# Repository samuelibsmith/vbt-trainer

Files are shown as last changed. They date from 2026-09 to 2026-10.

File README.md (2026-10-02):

# VBT Trainer

A DIY velocity-based training (VBT) device that measures barbell speed in real time. A spring-loaded spool with a 600 PPR rotary encoder measures bar displacement, and an ESP32 turns that into velocity, rep metrics, an on-device display, BLE output, and CSV logs.

## What it does

- Measures barbell velocity (±2% accuracy target) using a spring-loaded

  spool and 600 PPR rotary encoder

- Streams live velocity data over BLE to a phone app

- Logs session data to CSV for analysis

- Computes: MCV, peak velocity, velocity loss %, estimated 1RM, (using weight lifted: peak power, avg power)

## Hardware

| Microcontroller | ESP32 DevKit v1 | $9 | 

| Encoder | Taiss 600PPR | $18 | 

| Display | SSD1306 0.96" OLED | $3 |

| Battery | Samsung 30Q 18650 3000mAh 15A Battery | $4 |

| Battery Holder | Samsung 30Q 18650 3000mAh 15A Battery | $10 |

Full list: [`hardware/v_1_bom.csv`](hardware/v_1_bom.csv)

## Wiring

| Signal | ESP32 pin | Notes |
|---|---|---|
| Encoder channel A | GPIO 18 | 10 kOhm pull-up to 3.3 V |
| Encoder channel B | GPIO 19 | 10 kOhm pull-up to 3.3 V |
| OLED SDA | GPIO 21 | I2C address 0x3C |
| OLED SCL | GPIO 22 | |
| Reset button | GPIO 4 | <!-- TODO: to GND with internal pull-up? confirm from main.cpp --> |
| Battery + | Vin | also powers the encoder directly |

Pins are defined in [`firmware/include/config.h`](firmware/include/config.h). Wiring notes: [`docs/wiring_diagram.md`](docs/wiring_diagram.md).

> **Power warning:** the current design connects a bare 18650 directly to Vin with no protection circuit or charger. Use a protected cell or a charger/protection module, and never leave the cell unattended while charging. Expect voltage sag (and possible brownouts) as the cell nears empty.

## Getting started

### 1. Build the hardware
1a. Circuitry
Wire everything per the table above. Measure your own spool's effective diameter, because it sets the mm-per-count scale for every reading.
1b. 3D-Printed Housing
Unless you use the exact same tape measure internals from a (Ace 12 ft. L X 3/4 in. W Compact Tape Measure 1 pk), you will need to redesign both the key that translates torque from the spool to the encoder, and the spacing of encoder and the spool. The 3D model of the spool is a 3D replica of the actual spool, with the same measurements. If you order the same spool, the 3D-printed housing is good to go as is. 

### 2. Flash the firmware
Requirements: VS Code with the PlatformIO extension (or the `pio` CLI).

1. Open the `firmware/` folder in PlatformIO. Libraries install automatically from `platformio.ini`.
2. Set `SPOOL_DIAMETER_MM` in `firmware/include/config.h` to your measured spool diameter (the repo default is 37.47).
3. Build and upload: `pio run -t upload`
4. Open the serial monitor at 115200 baud to confirm output: `pio device monitor`

Key settings in `config.h`:

| Setting | Default | Meaning |
|---|---|---|
| `SAMPLE_RATE_HZ` | 200 | velocity calculation rate |
| `SMOOTHING_WINDOW` | 5 | moving-average length (samples) |
| `REP_START_VELOCITY` | 0.08 m/s | rep begins above this |
| `REP_END_VELOCITY` | 0.05 m/s | rep ends below this |
| `REP_MIN_DURATION_MS` | 150 | ignore shorter spikes |
| `BLE_BROADCAST_HZ` | 10 | BLE update rate |

### 3. Log data
Requires Python 3.9-3.12 (the pinned numpy 1.26 has no wheels for 3.13).

```bash
python -m venv .venv
source .venv/bin/activate        # Windows: .venv\Scripts\activate
pip install -r python/requirements.txt

python python/serial_logger.py

## Build Log

- [X] Phase 1: Sensor validation

- [ ] Phase 2: Firmware + Python pipeline

- [ ] Phase 3: Housing design and fabrication

- [ ] Phase 4: Phone app + dashboard

## License

MIT - see [LICENSE](LICENSE).

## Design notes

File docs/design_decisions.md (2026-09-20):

# Design Decisions Log

A running log of non-obvious choices made during the VBT build.

---

## Sensor: Linear transducer vs IMU

**Decision:** Linear position transducer (spool + rotary encoder)

**Reason:** IMUs require double-integration of acceleration to get position, which introduces significant drift. Direct position measurement via encoder gives cleaner velocity signal with no drift. Same method used by GymAware.

## Encoder: Signswise 600 PPR

**Decision:** 600 PPR incremental quadrature encoder

**Reason:** At 600 PPR with ~30mm spool, resolution is ~0.16mm per pulse. This is sufficient for barbell velocities (0.1–2.0 m/s). Higher PPR unnecessary and increases ESP32 interrupt load.

## Voltage: Pull-ups to 3.3V

**Decision:** 10kΩ pull-up resistors tied to 3.3V rail, not 5V 

**Reason:** ESP32 GPIO pins are not 5V tolerant. Pulling up to 3.3V keeps output signal within safe range without needing a level shifter.

## Smoothing: 5-sample moving average

**Decision:** Moving average with window size 5

**Reason:** TBD — will tune empirically during calibration testing.

## Spool: Ace Hardware 12' Tape Measure Spring-loaded spool

**Decision:** Choosing an existing spring-loaded spool versus a custom design

**Reason:** Tape measure retraction spools are a solved problem. The spring-loaded mechanism has plenty of power to retract a fishing line. The cost ~$9 is much more reasonable for a prototype than a custom design.

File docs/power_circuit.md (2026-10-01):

# Power Circuit (v1 redesign: protected single-cell supply)

Status: **design, not yet built or tested.** Verify every IC pin number against the manufacturer datasheets before ordering a PCB.

## Goals
- Inserting the 18650 backwards causes no damage
- Cell is protected against over-discharge, over-current, and short circuit
- The ESP32 and encoder get a stable 5 V rail across the full cell range (about 3.0-4.2 V)

## Block diagram

```
Holder+ -> Q1 (reverse-polarity PMOS) -> F1 (PTC) -> SW1 -> U2 (5 V boost) -> +5V -> ESP32 VIN, encoder
Holder- -> B- -> [Q2 FS8205A, controlled by U1 DW01A] -> GND (P-)
                                                          ESP32 3V3 -> OLED, encoder pull-ups
```

The protection IC switches the **negative** leg, so the positive rail is simply the output of Q1.

## Nets

| Net | Description |
|-----|---|
| `CELL+` | Holder positive contact |
| `B-` | Holder negative contact (cell side of the protection MOSFETs) |
| `VBAT` | Protected battery positive, after Q1 |
| `GND` | System ground (P-, load side of the protection MOSFETs) |
| `VSW` | VBAT after F1 and SW1 |
| `+5V` | Boost converter output |
| `+3V3` | ESP32 onboard 3.3 V output (used by OLED and pull-ups) |

## Bill of materials

| Ref | Part | Value / model | Package | Notes |
|-----|---|---|---|---|
| BT1 | Single 18650 holder | - | - | Use a protected or unprotected cell; this circuit adds protection either way |
| Q1 | P-channel MOSFET | AO3401A (or similar, Vgs(th) under 1.5 V, Rds(on) under 100 mOhm) | SOT-23 | Reverse-polarity protection |
| U1 | Battery protection IC | DW01A | SOT-23-6 | Over-discharge, over-current, short circuit |
| Q2 | Dual N-MOSFET | FS8205A (8205A) | TSSOP-8 | Pairs with U1 |
| R1 | Resistor | 100 Ohm | 0603 | U1 supply filter |
| R2 | Resistor | 1 kOhm | 0603 | U1 current-sense input |
| C1 | Capacitor | 0.1 uF | 0603 | U1 supply decoupling |
| F1 | Resettable fuse (PTC) | about 1.5 A hold | 1812 or radial | Last-resort overcurrent limit |
| SW1 | Slide switch | SPDT, rated 1 A or more | - | Main power switch |
| U2 | 5 V boost converter | Module or IC, at least 0.5 A output at 3.0 V input (e.g. Pololu U1V11F5) | - | Check the datasheet for input-current limits |
| C2 | Capacitor | 10 uF | 0805 | Optional: extra bulk at U2 input |
| R3, R4 | Resistors | 10 kOhm | 0603 | Encoder A/B pull-ups to 3V3 |
| U3 | ESP32 DevKit v1 | - | - | 30-pin DevKit v1 |
| DS1 | OLED | SSD1306 0.96" I2C | - | 4-pin module |
| ENC1 | Rotary encoder | 600 P/R, 2-channel, NPN open-collector, 5-24 V | - | See wiring below |
| SW2 | Momentary button | - | - | Reset / rep button on GPIO 4 |

## Wiring

### Reverse-polarity protection

| From | To |
|---|----|
| BT1 + (`CELL+`) | Q1 **drain** (SOT-23 pin 3) |
| Q1 **source** (pin 2) | `VBAT` |
| Q1 **gate** (pin 1) | `GND` |

Correct insertion turns Q1 on. Reversed, Q1 stays off and blocks current.

### Cell protection (U1, Q2)

| From | To | Notes |
|---|----|---|
| `VBAT` | R1 (100 Ohm), then U1 pin 5 (VCC) | |
| C1 | U1 VCC to U1 GND | Place close to U1 |
| U1 pin 6 (GND) | `B-` | |
| U1 pin 1 (OD) | Q2 pin 4 (G1) | Over-discharge gate |
| U1 pin 3 (OC) | Q2 pin 5 (G2) | Over-charge gate |
| U1 pin 2 (CS) | R2 (1 kOhm), then `GND` | Current sense |
| U1 pin 4 (TD) | not connected | Test pin |
| Q2 pins 2, 3 (S1) | `B-` | |
| Q2 pins 6, 7 (S2) | `GND` | |
| Q2 pins 1, 8 (D) | tie together, no other connection | Shared drain |
| BT1 - | `B-` | |

### Power path

| From | To |
|---|----|
| `VBAT` | F1 |
| F1 | SW1 common |
| SW1 output (`VSW`) | U2 VIN |
| U2 GND | `GND` |
| U2 VOUT (`+5V`) | ESP32 **VIN** pin |
| ESP32 GND | `GND` |

### Encoder (ENC1)

NPN open-collector outputs only pull a signal to ground, so each output needs a pull-up. **Pull up to 3.3 V, never 5 V**, because ESP32 GPIOs are not 5 V tolerant.

| Encoder wire (typical colors, verify on your unit) | To |
|---|----|
| Red (V+) | `+5V` |
| Black (0 V) | `GND` |
| Green (A) | ESP32 GPIO 18, and R3 (10 kOhm) to `+3V3` |
| White (B) | ESP32 GPIO 19, and R4 (10 kOhm) to `+3V3` |
| Shield (if present) | `GND` |

### Display (DS1) and button

| From | To |
|---|----|
| DS1 VCC | `+3V3` |
| DS1 GND | `GND` |
| DS1 SDA | ESP32 GPIO 21 |
| DS1 SCL | ESP32 GPIO 22 |
| SW2 one side | ESP32 GPIO 4 |
| SW2 other side | `GND` (assumed, confirm against `main.cpp`) |

## Bring-up checklist
1. Inspect all joints. Check continuity that `VBAT` and `GND` are not shorted, with no cell installed.
2. With SW1 **off**, insert the cell **backwards** deliberately. Measure `VBAT` and `+5V`: both should read about 0 V and nothing should get warm. Remove the cell.
3. Insert the cell correctly, SW1 still off. `VBAT` should read the cell voltage.
4. Turn SW1 on. `+5V` should read about 5 V and the ESP32 should boot.
5. Confirm encoder counts and display before doing anything else.

## Notes and limits
- **Charging is external.** Charge the cell in a separate 18650 charger. Adding an onboard TP4056-class charger is a future revision.
- **Keep SW1 off when connecting USB** so the USB supply and boost converter do not feed VIN together.
- **Protection cutoffs** for DW01A are around 2.4 V (over-discharge) with an over-current trip of several amps; check the datasheet for exact thresholds.
- This is a hobby design that has not been independently reviewed. Treat it as a starting point and do not leave a lithium cell unattended while testing.

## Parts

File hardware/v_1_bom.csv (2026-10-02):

Ref | Qty | Part | Key spec | Notes | Link to Buy
U3 | 1 | ESP32 DevKit v1 | ESP32-WROOM-32, USB, 3V3 and VIN pins | 30-pin or 38-pin both work | http://amazon.com/Development-Compatible-Supports-Dual-Core-Microcontroller/dp/B0FPLS7XDM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
ENC1 | 1 | Rotary encoder | 600 P/R, 2-channel, NPN open-collector, 5-24 V, 6 mm shaft |  | https://www.amazon.com/dp/B07JM9YRTQ?lv=shuf&channelId=500&plpRedirect=mhFallback
DS1 | 1 | OLED display | SSD1306, 0.96 in, 128x64, I2C | Firmware uses address 0x3C | amazon.com/UCTRONICS-SSD1306-Self-Luminous-Display-Raspberry/dp/B072Q2X2LL/ref=sr_1_6?crid=3DOX8Y4UI2PD6&dib=eyJ2IjoiMSJ9.z259gjIsNpIAfONgHGpTbSRqoqPFDFXhWZRag8Bblgf4_0T06BFWpd2v7jx2iUymEyqv1FezfHEzqE_sTzU-TVdDscfZy7ZZ69cgJI0-vkZ_2_5oocDjsiddisiYbPTWiEp0MKLVdsu6boR2DG2ubOv-elv5FY_U-ATUU9SR3mC2mE51OYS6bWM72Ub06_ofopWxcF1VX9CpeYeNmFi8sbJeN4LFR0jhabFZz91flq4.BYX3qmEq7juO6cMsYyJv2QjN2FNC9sa0lZnExs5kk6Y&dib_tag=se&keywords=SSD1306%2C+0.96+in%2C+128x64%2C+I2C&qid=1790949157&sprefix=ssd1306%2C+0.96+in%2C+128x64%2C+i2c%2Caps%2C177&sr=8-6
BT1 | 1 | 18650 cell (protected) | Li-ion about 3000 mAh, built-in protection board | Check length fits the holder | https://www.18650batterystore.com/products/samsung-30q
 | 1 | Single 18650 holder |  |  | https://www.amazon.com/FORIOT-Battery-Compartment-Support-Charging/dp/B0CJR1Y967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
Q1 | 1 | AO3401A P-channel MOSFET | SOT-23, -30 V, about -4 A | Alternative: SI2301; Reverse-polarity protection | https://www.digikey.com/en/products/detail/alpha-omega-semiconductor-inc/AO3401A/1855773
F1 | 1 | Resettable fuse (PTC) | About 1.5 A hold | Optional - can find own if wanting to add the current protection
SW1 | 1 | Power switch | Rated 2 A or more | Optional - can find own if wanting to add the current protection
U2 | 1 | 5 V boost converter | At least 0.5 A output at 3.0 V input | e.g. Pololu U1V11F5; check datasheet | https://www.pololu.com/product/2562
SW2 | 1 | Momentary push button |  | Reset button on GPIO 4 | https://www.dfrobot.com/product-612.html
R3, R4 | 2 | Resistor | 10 kOhm 1/4 W | Encoder A/B pull-ups to 3V3
 | 1 | Spool and spring tether mechanism | 37.47 mm effective diameter | Measure your own spool, but I linked the exact model here | https://www.acehardware.com/departments/tools/measure-and-marking-tools/tape-measures/2037164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
 | 1 | Perfboard or breadboard, hookup wire, connectors
 | 1 | External 18650 charger |  | Charging is off-board in v1
 | 1 | M3x4mm Heat Inserts
 | 1 | M3 assorted screws socket cap head

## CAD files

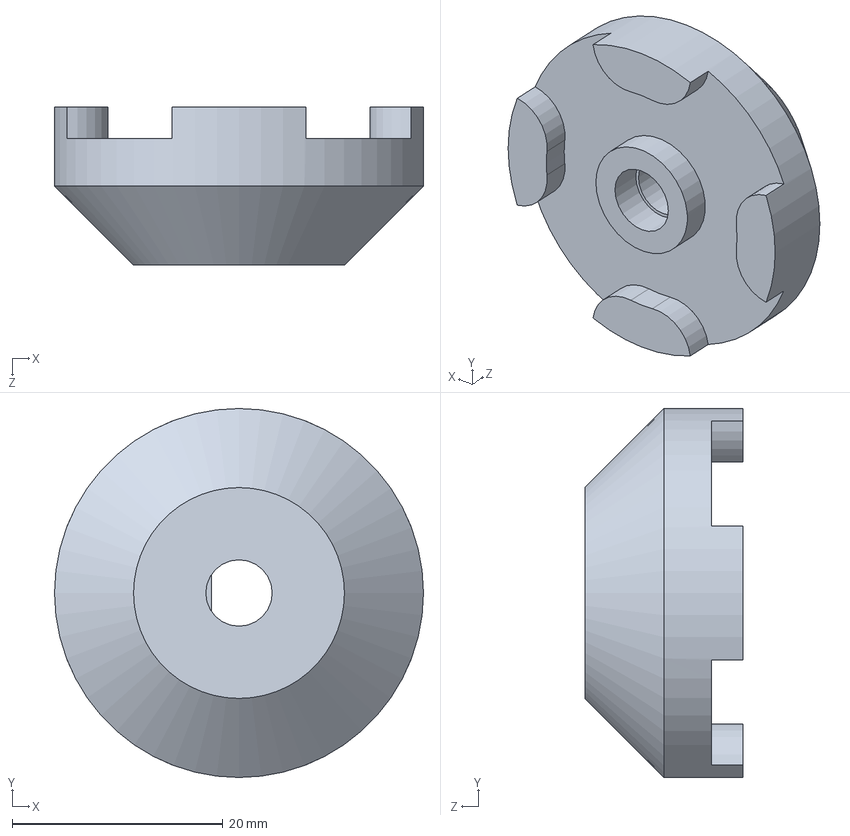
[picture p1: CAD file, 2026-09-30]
hardware/cad/VBT_Encoder_Spool_Key.SLDPRT
35.0 x 35.0 x 15.0 mm

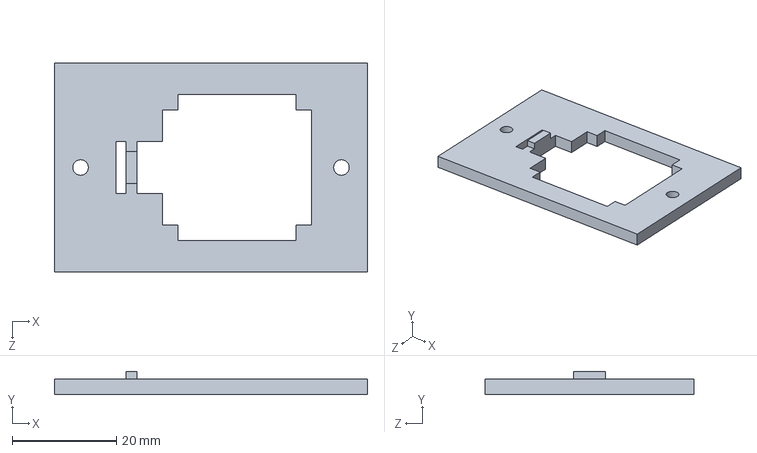
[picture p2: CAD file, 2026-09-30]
hardware/cad/ScreenBracket.SLDPRT
60.0 x 4.50 x 40.0 mm

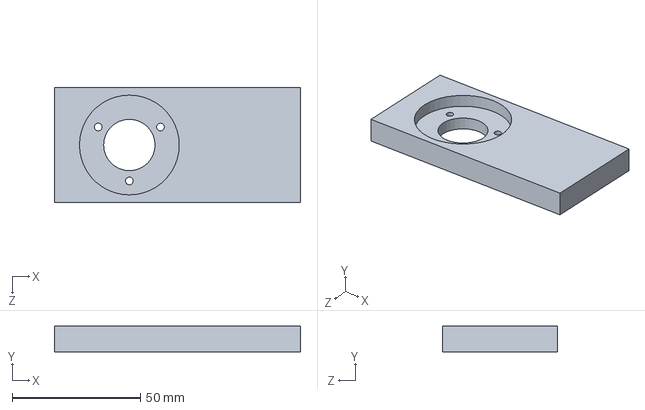
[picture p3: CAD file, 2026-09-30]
hardware/cad/VBT_EncoderSide_Wall.SLDPRT
95.8 x 10.0 x 44.8 mm

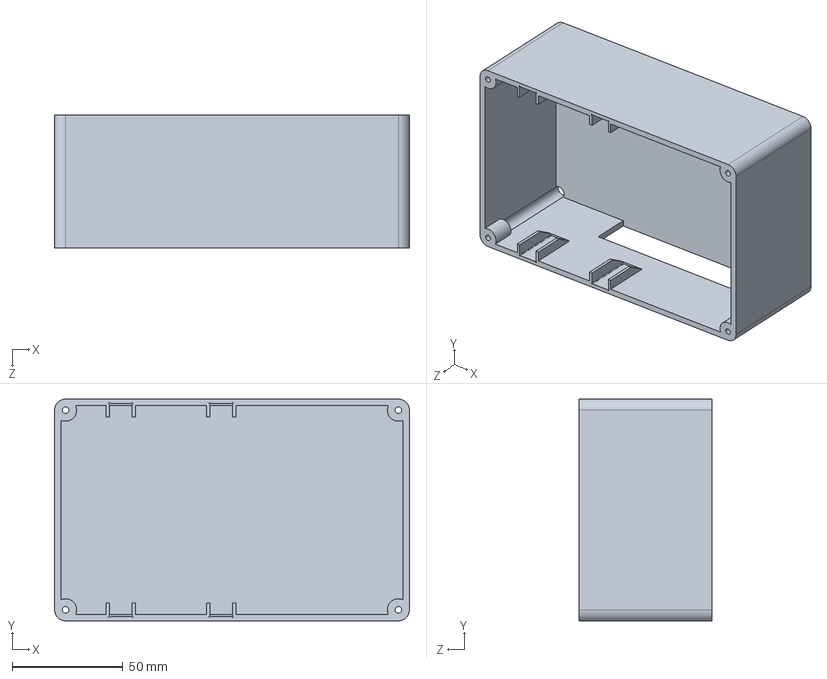
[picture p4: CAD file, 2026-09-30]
hardware/cad/VBT_Container_Base.SLDPRT
160.0 x 100.0 x 60.0 mm

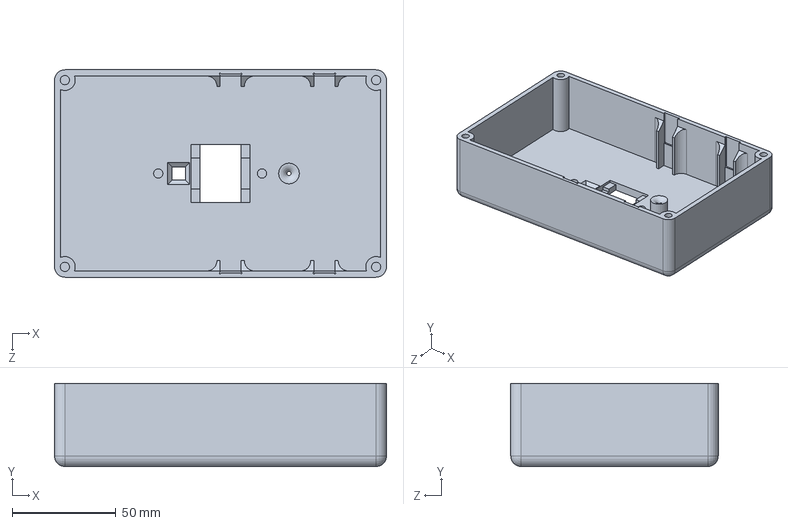
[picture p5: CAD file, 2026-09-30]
hardware/cad/VBT_Container_Lid.SLDPRT
160.0 x 40.0 x 100.0 mm

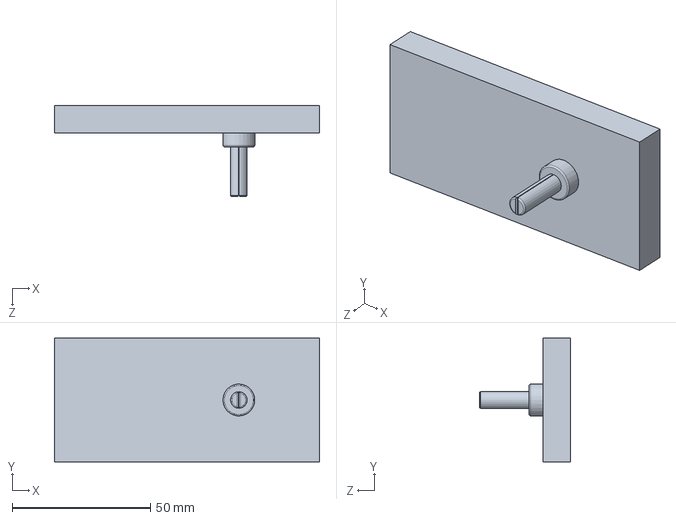
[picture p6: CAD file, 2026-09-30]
hardware/cad/VBT_SpoolSide_Wall.SLDPRT
95.8 x 44.8 x 33.0 mm

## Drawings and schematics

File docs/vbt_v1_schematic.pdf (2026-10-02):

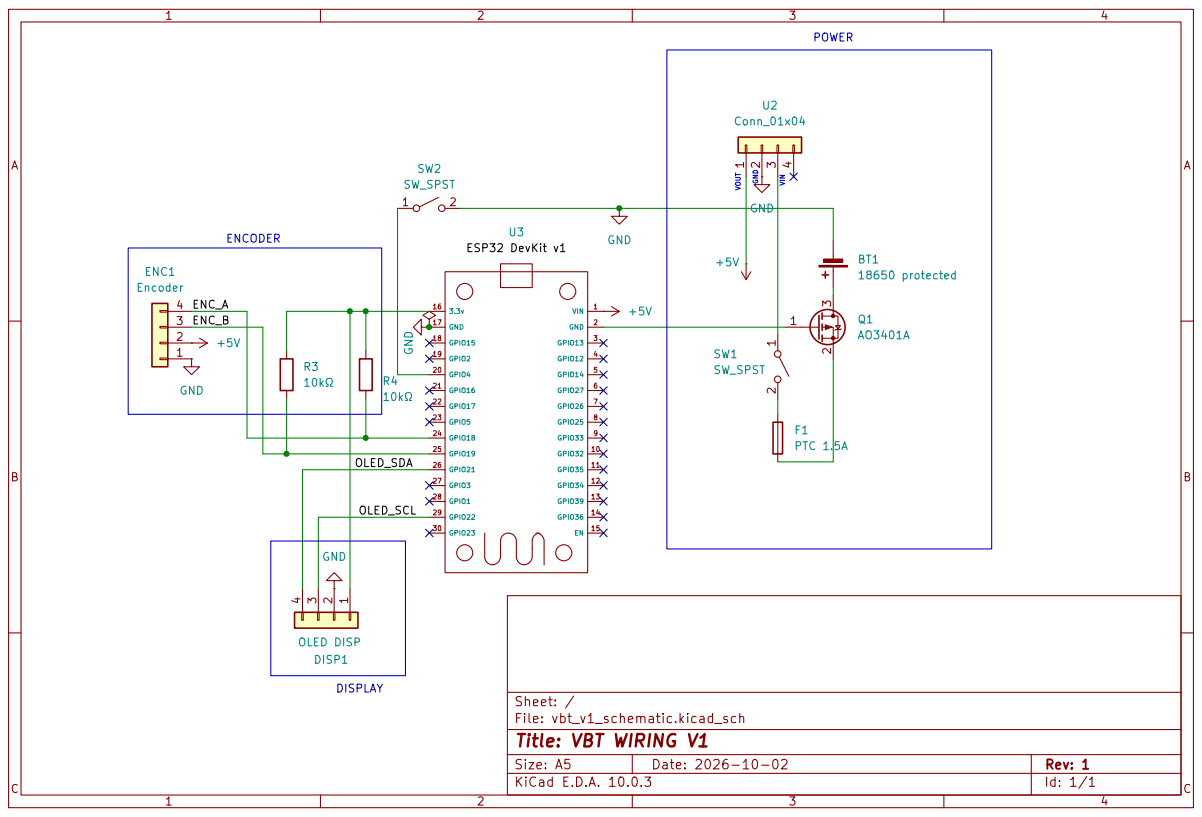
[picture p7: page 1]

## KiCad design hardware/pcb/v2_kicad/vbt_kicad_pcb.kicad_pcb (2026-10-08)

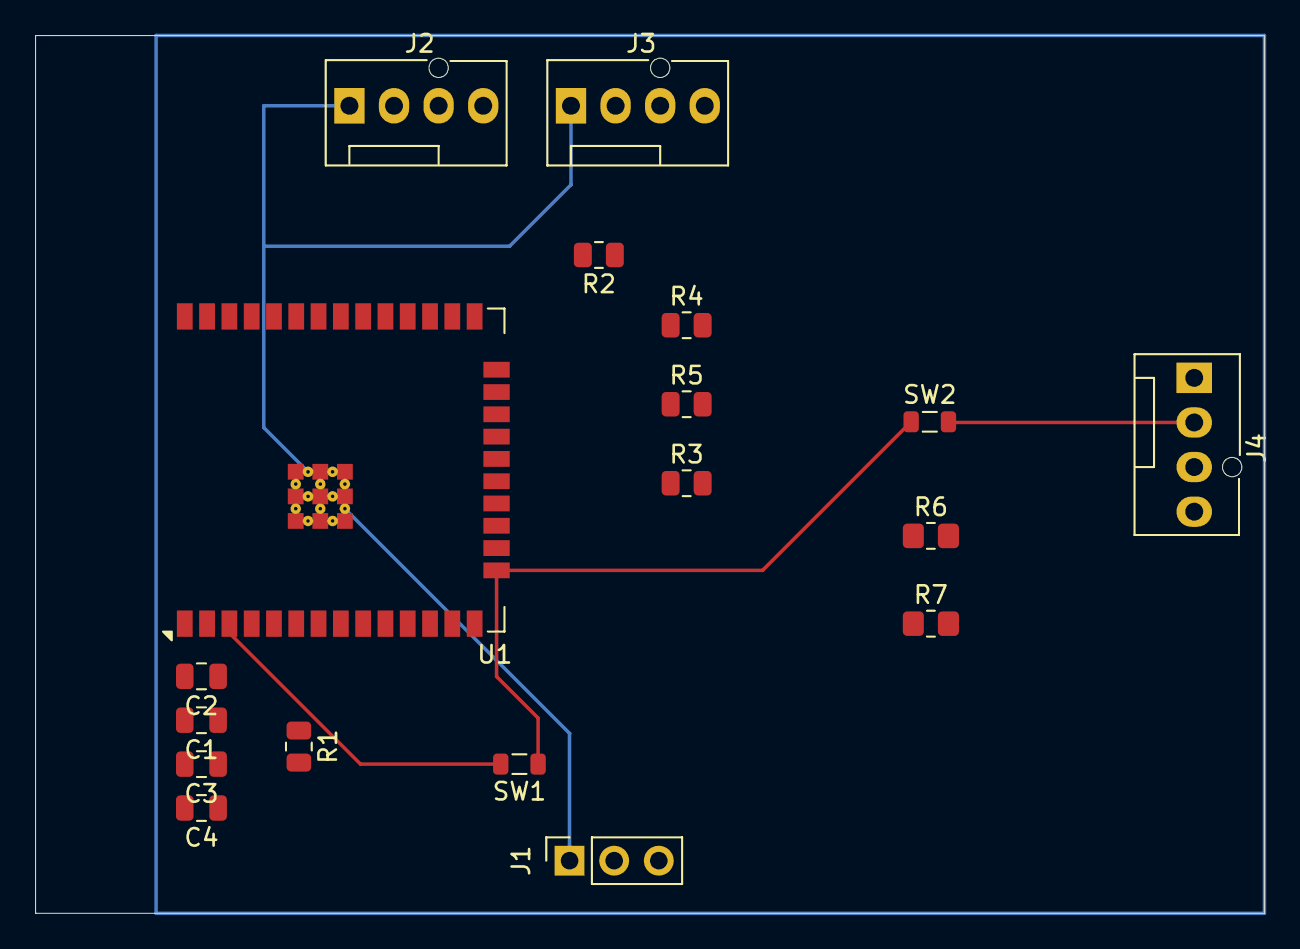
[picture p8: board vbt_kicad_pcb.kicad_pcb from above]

Board: 2 copper layers, 70.0 x 50.0 mm, 18 parts (0 on the bottom side), 10 nets.

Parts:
C1: 10 µF; C_0805_2012Metric
C2: 100 nF; C_0805_2012Metric
C3, C4: 1 µF; C_0805_2012Metric
J1: Conn_01x03; PinSocket_1x03_P2.54mm_Vertical
J2, J3, J4: Conn_01x04; FanPinHeader_1x04_P2.54mm_Vertical
R1, R2: R; R_0805_2012Metric
R3: 10k; R_0805_2012Metric
R4, R5: 4.7k; R_0805_2012Metric
R6, R7: 100k; R_0805_2012Metric_Pad1.20x1.40mm_HandSolder
SW1, SW2: SW_Push; L_0805_2012Metric
U1: ESP32-WROOM-32E

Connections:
+3V3: C1.1, C2.1, J3.2, J4.4, R1.1, R2.1, R3.1, R4.1, R5.1, U1.2 (VDD)
/+5V: J2.2, J4.1
/ENC_A: J2.4, R2.2, U1.30 (IO18)
/ENC_B: J2.3, R3.2, U1.31 (IO19)
/I2C_SCL: J3.4, R5.2, U1.36 (IO22)
/I2C_SDA: J3.3, R4.2, U1.33 (IO21)
/VBAT_SENSE: R6.2, U1.6 (IO34)
GND: C1.2, C2.2, C3.2, C4.1, C4.2, J1.1, J2.1, J3.1, J4.2, R7.1, SW1.1, SW2.1, SW2.2, U1.1 (GND), U1.15 (GND), U1.25 (IO0), U1.38 (GND), U1.39 (GND)
unnamed: J4.3, R6.1, R7.2
unnamed: C3.1, R1.2, SW1.2, U1.3 (EN)

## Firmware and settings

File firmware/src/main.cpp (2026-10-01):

/*
 VBT Trainer Project - Samuel Smith - Spring 2026
sibsmith@bu.edu | sibsmith.ithaca@gmail.com
*/
#include <Arduino.h> // Core: pinMode, digitalRead, millis, Serial
#include <ESP32Encoder.h> // Harware pulse counter -- performs better than interrupts
#include <Adafruit_GFX.h>      // Graphics base library for OLED
#include <Adafruit_SSD1306.h>  // OLED driver
#include <Wire.h> //I2C protocol -- needed for OLED
#include <NimBLEDevice.h> // Bluetooth Low Energy
#include "config.h" //imports custom pin definitions and constants

ESP32Encoder encoder;

// Velocity Tracking
float velocityBuffer[SMOOTHING_WINDOW]; //Circular buffer for moving average
int bufferIndex = 0; //Index for tracking buffer position
float smoothVelocity = 0.0; //Value of the smoothed velocity
float peakVelocity = 0.0; //Highest velocity in the calculated rep window
long lastPulseCount = 0; //Encoder count at last velocity sample
unsigned long lastSampleTime = 0; //Timestamp of last velocity sample (ms)

// Rep detection
bool repInProgress = false; // Checks to see if we are currently in a rep
int repCount = 0; // Total reps in the session
float repStartVelocity = 0.0; // Velocity at the start of the rep 
float meanConcentricVelo = 0.0; //Mean Concentric Velocity for the completed repetition
// **Mean Concentric Velocity (MCV)** Average velocity of the barbell during the rep
float velocitySumThisRep = 0.0; // Sum of the velocity samples during concentric phase
int samplesThisRep = 0; // Number of sampels taken during the concentric phase of the rep
unsigned long repStartTime = 0; // When this rep started (ms)

// Session Tracking
float setPeakVelocity = 0.0; // MCV of the rep with the highest velocity (to calculate velocity loss %)
float velocityLoss = 0.0; // Signed percent change from peak rep to most recent rep
// OLED 
Adafruit_SSD1306 display(128, 64, &Wire, -1);

// Bluetooth LE 
NimBLEServer* bleServer = nullptr;
NimBLECharacteristic* bleCharVelocity = nullptr;
bool bleClientConnected = false;
unsigned long lastBLEUpdate = 0; // timestamp of last BLE broadcast
class ServerCallbacks : public NimBLEServerCallbacks {
    void onConnect(NimBLEServer* server) override {

        bleClientConnected = true;

        Serial.println("BLE: phone connected");

    }
        void onDisconnect(NimBLEServer* server) override {

        bleClientConnected = false;

        Serial.println("BLE: phone disconnected — advertising again");

        server->startAdvertising();  // Auto-restart advertising so phone can reconnect

    }
};

void setupBLE(){
    NimBLEDevice::init(BLE_DEVICE_NAME);  // Initialize with your device name
    bleServer = NimBLEDevice::createServer();
    bleServer->setCallbacks(new ServerCallbacks());
    //Create the service - service being the catagory of data, in this case vbt velocity data
    NimBLEService* service = bleServer->createService(SERVICE_UUID);
    bleCharVelocity = service->createCharacteristic(CHARACTERISTIC_UUID, NIMBLE_PROPERTY::NOTIFY);
    service->start(); 
    // begins advertizing existence so phone can connect 
    NimBLEAdvertising* advertising = NimBLEDevice::getAdvertising();
    advertising->addServiceUUID(SERVICE_UUID);
    advertising->start();
    Serial.println("BLE: advertising as '" BLE_DEVICE_NAME "'");
}
// HELPER FUNCTIONS ---------------------
// calculateVelocity: Returns raw velocity in m/s when called every 200Hz/5ms in loop()
float calculateVelocity() {
    unsigned long now = millis(); // Gets current time in ms
    long nowCount = encoder.getCount(); // Gets the current encoder pulse count
    unsigned long dt_ms = now - lastSampleTime; // Time delta between last sample (ms)
    long dp = (nowCount - lastPulseCount) * CONCENTRIC_SIGN; // Pulses since last sample
    // Update "last" values for next function call
    lastSampleTime = now;
    lastPulseCount = nowCount;
    //Safeguard: if not time has passed, avoide devide-by-zero error
    if (dt_ms == 0) return 0.0;
    //Convert pulses to mm and milliseconds to seconds to get velocity
    //Calculation is (meters/second) = pulses * mm/pulse * 1 meter / 1000 mm * 1000 ms/1s * 1/dt_ms
    float displacement_mm = dp * MM_PER_PULSE; //total mm moved
    float velocity_ms = (displacement_mm/1000.0)/(dt_ms/1000.0); //mm -> meters, ms -> seconds (meters/second)
    //Given we only want the upward velocity, the velocity must have a sign to denote direction
    return velocity_ms;
}

// logToSerial: logs the timestamp (ms), rawVelocity value, and smoothVel value in csv format
void logToSerial(unsigned long timestamp, float rawVelocity, float smoothVel, int rep) {
    // Format: timestamp_ms, raw_velocity, smooth_velocity, rep_number
    Serial.print(timestamp);
    Serial.print(",");
    Serial.print(rawVelocity, 4);   // 4 decimal places
    Serial.print(",");
    Serial.print(smoothVel, 4);
    Serial.print(",");
    Serial.println(rep);            // println adds newline — Python reads line by line
}

//updateDisplay: called after each rep is completed and at every 100ms interval during the rep
void updateDisplay(float mcv, int reps, float velocity, float vLoss) {
    display.clearDisplay(); //Clear display of any existing text
    display.setTextColor(SSD1306_WHITE);
    //LINE 1: Large text displaying LIVE VELOCITY
    display.setTextSize(2); 
    display.setCursor(0, 0);
    display.print(mcv, 2);   // Round velocity to 2 decimal places
    display.print(" m/s");
    //LINE 2: Displays a rep counter for current exercise
    display.setTextSize(1);
    display.setCursor(0, 22);
    display.print("Reps: "); //Prints "reps" before the number that gets updated
    display.print(reps);
    //LINE 3: Last rep MCV
    display.setCursor(0, 32);
    display.print("Peak: ");
    display.print(velocity, 2); //Rounds mcv to 2 decimal places, consistent with velo
    display.print(" m/s");
    // Line 4: Velocity loss %
    display.setCursor(0, 42);
    display.print("VL%: ");
    display.print(vLoss, 1);
    display.print("%");
    // Line 5: BLE status
    display.setCursor(0, 54);
    display.print(bleClientConnected ? "BLE: connected" : "BLE: waiting...");
    display.display(); //Push buffer to screen — nothing shows until this is called
}

//sendBleUpdate: When called, packages current rep data as JSON string 
//formatted as {"v":1.23,"reps":3,"mcv":1.18,"vl":4.2} and sends as BLE packet
void sendBleUpdate(float velocity, int reps, float mcv, float vLoss) {
    if (!bleClientConnected) return;  // Immedate return if not bluetooth connection is established
    // Sample JSON string is as follows: {"v":1.23,"reps":3,"mcv":1.18,"vl":4.2}
    char jsonBuffer[80]; // If number of reps gets too high, this may crash the buffer of only 80
    snprintf(jsonBuffer, sizeof(jsonBuffer),
        "{\"v\":%.2f,\"reps\":%d,\"mcv\":%.2f,\"vl\":%.1f}", velocity, reps, mcv, vLoss);
    bleCharVelocity->setValue((uint8_t*)jsonBuffer, strlen(jsonBuffer));
    bleCharVelocity->notify();  //Push to any subscribed phone
}

// smoothVelocityReading: takes the float of the newest velocity sample "newSample" 
// and returns a new smoothed average given the defined SMOOTHING_WINDOW
float smoothVelocityReading(float newSample){
    velocityBuffer[bufferIndex] = newSample; // Stores new sample
    bufferIndex = (bufferIndex + 1) % SMOOTHING_WINDOW; // Advances buffer index 
    // % (modulus) wraps back to 0
    // Calculate the average of all samples in buffer
    float sum = 0.0;
    for (int i = 0; i<SMOOTHING_WINDOW; i++){
        sum += velocityBuffer[i];
    }
    return sum/SMOOTHING_WINDOW;
}


void setup(){
    //_________________________ SERIAL _________________________
    Serial.begin(115200);
    Serial.println("VBT Trainer starting...");
    //_________________________ BUTTON _________________________
    pinMode(RESET_BUTTON_PIN, INPUT_PULLUP);

    // ENCODER
    ESP32Encoder::useInternalWeakPullResistors = puType::up; //enable internat pull-up resistors
    encoder.attachFullQuad(ENCODER_PIN_A, ENCODER_PIN_B);
    encoder.setCount(0); // Zero the counter when starting up
    Serial.println("Encoder initialized on GPIO " + String(ENCODER_PIN_A) + "and" + String(ENCODER_PIN_B));
    //Initialized velocity buffer to be zero
    for (int i=0; i<SMOOTHING_WINDOW; i++){
        velocityBuffer[i] = 0.0;
    }
    
    //_________________________ OLED _________________________
    Wire.begin(OLED_SDA_PIN, OLED_SCL_PIN);  // Start I2C on the pins from config.h
    if (!display.begin(SSD1306_SWITCHCAPVCC, OLED_ADDRESS)) {
        // If OLED doesn't initialize, print error and continue without it
        Serial.println("WARNING: OLED not found — check wiring"); 
        // Prints a display isn't functioning message   
    } else {
        // initialization messages
        display.clearDisplay();
        display.setTextSize(1);
        display.setTextColor(SSD1306_WHITE);
        display.setCursor(0, 0);
        display.println("VBT Trainer");
        display.println("Ready... ");
        display.clearDisplay();
        display.println("Setup complete. Waiting for lifts...");
        Serial.println("OLED initialized"); // Prints initialization to Serial
    }
    //_________________________ BLE _________________________
    setupBLE();
    //_________________________ Record Start Time _________________________
    lastSampleTime = millis(); //Grabs the current time
    Serial.println("Setup complete. Waiting for lifts..."); 

}
/*
void loop(){
    int stateA = digitalRead(18);
    int stateB = digitalRead(19);
    Serial.print("A: ");
    Serial.print(stateA);
    Serial.print("B ");
    Serial.print(stateB);
    delay(100);
} 
*/
void loop() {
    int buttonState = digitalRead(RESET_BUTTON_PIN); // Immediately reads 
    if (buttonState == 0) {
        repCount = 0;
        repInProgress = false;
        meanConcentricVelo = 0.0;
        peakVelocity = 0.0;
        velocityLoss = 0.0;
        setPeakVelocity = 0.0;
        updateDisplay(0.00, 0, 0.00, 0);
    }
    unsigned long now = millis(); // Get current time once per loop iteration
    //TASK 1: Calculate velocity at 200Hz
    if (now - lastSampleTime >= (1000/SAMPLE_RATE_HZ)){
        float rawVel = calculateVelocity();
        smoothVelocity = smoothVelocityReading(rawVel);
        logToSerial(now, rawVel, smoothVelocity, repCount);    
        //Task 1a: Rep detection
        //Check to see if a rep is already in progress
        if (!repInProgress) {
            //If rep is not in progress, one is started
            
            if (smoothVelocity > REP_START_VELOCITY) {
                repInProgress = true; //change bool for reps
                repStartTime = now; //set the rep start time to now
                peakVelocity = smoothVelocity; //set the peak velocity to the velocity at the start
                velocitySumThisRep = smoothVelocity; //Begin to sum velocities with first sample
                samplesThisRep = 1; 
            }
        }
        // Else means rep is in progress - data collection is active
        else {
            velocitySumThisRep += smoothVelocity;
            samplesThisRep ++;
            if (smoothVelocity > peakVelocity) {
                peakVelocity = smoothVelocity;
            }

            //Check to see if the rep has ended based on thresholds set in config.h
            //The two criteria for this are: 
            //1. The velocity drops below threshold. 
            //2. The duraction minimum is met to prevent false positive reps
            bool velocityDropped = smoothVelocity < REP_END_VELOCITY; 
            bool longEnough = (now - repStartTime) > REP_MIN_DURATION_MS;
            if (velocityDropped && longEnough){
                //Below is calculated when the rep is complete
                repInProgress = false; //program knows rep is over
                repCount ++; //count the final rep
                meanConcentricVelo = velocitySumThisRep / samplesThisRep; // calculate MCV
                // Store first rep velocity for VL% calculation
                /* Logic of VL% - Velocity Loss % = (peakRep - repN) / peakRep * 100
                -If on rep1 --> assign peak to rep1
                -If on rep2 or later, there are three cases:
                    1. repN < rep1 --> imediately calculate velocity change
                    2. repN+1 > repPeak --> calculate velocity change AND set peak to repN+1 MCV
                    3. repN+1 = repN --> velocity change is 0, but need to check for this case
                */

                if (repCount == 1) {
                    setPeakVelocity = meanConcentricVelo;
                }
                if (setPeakVelocity > 0){
                    velocityLoss = ((setPeakVelocity - meanConcentricVelo)/ setPeakVelocity) * 100.0 * -1; // Case 1 (and 3)

                    if (meanConcentricVelo > setPeakVelocity){
                        // After loss (or gain in this case) is calculated, set the new repPeak
                        setPeakVelocity = meanConcentricVelo;
                    }
                }
                
                // Log completed rep summary (starts with # so Python can parse separately)
                Serial.print("# REP,");
                Serial.print(repCount);
                Serial.print(",");
                Serial.print(meanConcentricVelo, 3);
                Serial.print(",");
                Serial.print(peakVelocity, 3);
                Serial.print(",");
                Serial.println(velocityLoss, 1);
                // Update display immediately after rep
                updateDisplay(meanConcentricVelo, repCount, peakVelocity, velocityLoss);

            }
        }
    }
    // Task 2: Send BLE update at 10Hz
    if (now - lastBLEUpdate >= (1000 / BLE_BROADCAST_HZ)) {
        lastBLEUpdate = now;
        sendBleUpdate(smoothVelocity, repCount, meanConcentricVelo, velocityLoss);
    }
    
}

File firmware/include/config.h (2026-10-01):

#pragma once

// ── Encoder ──────────────────────────────────────────

#define ENCODER_PIN_A     18      // GPIO pin for encoder channel A

#define ENCODER_PIN_B     19      // GPIO pin for encoder channel B

#define ENCODER_PPR       600     // Pulses per revolution

#define DIRECTION_CW 0              // defines a clockwise direction

#define DIRECTION_CCW 1             // defines a counterclockwise direction

// ── Spool geometry ───────────────────────────────────

#define SPOOL_DIAMETER_MM 37.47    // in mm

#define SPOOL_CIRCUMFERENCE_MM (SPOOL_DIAMETER_MM * 3.14159)

#define MM_PER_PULSE (SPOOL_CIRCUMFERENCE_MM / (ENCODER_PPR * 4)) // x4 for quadrature

// #define MM_PER_PULSE (SPOOL_CIRCUMFERENCE_MM / (ENCODER_PPR * 2)) // x2 for 2 PPR

// ── Velocity calculation ──────────────────────────────

#define SAMPLE_RATE_HZ    200     // How often velocity is calculated

#define SMOOTHING_WINDOW  5       // Moving average window size (samples)

#define CONCENTRIC_SIGN  1
// Sign of the encoder count change when the bar moves UP (+1 or -1).
// If velocity reads negative on the way up, flip this.


// ── Rep detection ─────────────────────────────────────

#define REP_START_VELOCITY  0.08  // m/s — velocity above this = concentric started

#define REP_MIN_DURATION_MS 150   // ms  — ignore spikes shorter than this

#define REP_END_VELOCITY    0.05  // m/s — velocity below this = rep ended

// ── BLE ───────────────────────────────────────────────

#define BLE_DEVICE_NAME   "VBT-Trainer-V_0"

#define BLE_BROADCAST_HZ  10      // How often to send BLE packet

#define SERVICE_UUID        "209ec59d-a3ea-40c6-ae45-e495047cff05"

#define CHARACTERISTIC_UUID "85f3ab78-fdfb-4c16-8b9e-1a324e287fb3"

// ── Display ───────────────────────────────────────────

#define OLED_SDA_PIN      21

#define OLED_SCL_PIN      22

#define OLED_ADDRESS      0x3C

// ── Button ───────────────────────────────────────────

#define RESET_BUTTON_PIN 4 

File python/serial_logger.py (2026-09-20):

import serial
import serial.tools.list_ports
import csv 
import os
import time
from datetime import datetime

BAUD_RATE = 115200 # baude rate means bits per second
OUTPUT_DIR = os.path.join(os.path.dirname(__file__), '..', 'data', 'sessions') # build sessions directory
#where data will be stored in vbt-trainer/data/sessions
HEADER_ROW = ["timestamp_ms", "raw_velocity", "smooth_velocity", "rep_num"]
# defines header row in csv. Must match serial output

def find_esp32_port():
    """
    Automatically finds the port which the ESP32 is connected to.
    """
    ports = serial.tools.list_ports.comports() #finds and lists all ports visible

    for port in ports:
        desc = port.description.lower() # gets the human-readable description of each port, in lower case
        if any(chip in desc for chip in ['cp210', 'ch340', 'uart', 'esp32']):
            print(f"Found ESP32 on {port.device} ({port.description})")

            return port.device
    
    print("Could not auto-detect ESP32") # in case detection fails

    # The followings a manual method from the user

    for i, port in enumerate(ports):
        print(f" [{i}] {port.device} - {port.description}")

    choice = int(input("Enter port number: "))
    
    return ports[choice].device

def create_session_files():
    """
    Creates the output directory if it doesn't exists, the builds timestamped
    file paths for this session's raw data and rep data
    """
    os.makedirs(OUTPUT_DIR, exist_ok=True) # creates the directory, and any missing parent directories

    timestamp = datetime.now().strftime("%Y-%m-%d_%H-%M")
    # gets the current date and time formatted as Year-Month-Day_Hour-Minute

    # builds the raw and rep paths with timestamp formatted names

    raw_path = os.path.join(OUTPUT_DIR, f"{timestamp}_raw.csv")
    rep_path = os.path.join(OUTPUT_DIR, f"{timestamp}_reps.csv")

    return raw_path, rep_path

def parse_rep_summary(line):

    """
    Parses the data from each rep and writes it into the csv
    """
    parts = line.replace('# REP,', '').split(',') # replaces the # rep identifier and splits the line by commas

    try:
        rep_num, mcv, peak, vl= [float(p) for p in parts]
        return [int(rep_num), mcv, peak, vl]
    
    except ValueError as e:
        print(f" Warning: malformed rep line: {line} ({e})")
        return None
    

def run_logger(port):
    """
    Main logging loop:
    1. connects to the ESP32 on given port 
    2. reads lines until Ctrl+C inputted
    3. saves data to timestamped CSV files
    """

    raw_path, rep_path = create_session_files() # creates the output files and gets their paths

    # Provide user with information on where data will be stored
    print(F"\nLogging to:")
    print(F"Raw samples: {raw_path}")
    print(F"Rep samples: {rep_path}")
    print(F"\nPress Ctrl+C to stop.\n")


    raw_file = open(raw_path, 'w', newline='') # opens file for writing 
    rep_file = open(rep_path, 'w', newline='')

    raw_writer = csv.writer(raw_file) # wraps the file object so writing can be done to it
    rep_writer = csv.writer(rep_file)

    raw_writer.writerow(HEADER_ROW)
    rep_writer.writerow(['rep_num', 'mcv', 'peak_velocity', 'vl_percent'])

    try:
        ser = serial.Serial(port, BAUD_RATE, timeout=1)
        time.sleep(2.5)
        ser.reset_input_buffer()
        #ser = serial.Serial(port, BAUD_RATE, timeout=1) #Opens the serial port connection to ESP32
        print(f"Connected to {port} at {BAUD_RATE}\n") #Alert user of connection success
        
        while True:
            #Reads line fron serial until a \n is read
            line = ser.readline().decode('utf-8', errors='replace').strip()
            if '# REP' in line:
                print(f"REP LINE: {repr(line)}")
    
            if not line:
                continue # if readline times out we want the program to continue running

            # --- Branch 1: Rep summary lines ---
            if line.startswith('# REP,'):
                
                print(f' {line}\n')
                parsed = parse_rep_summary(line) # parse the line into a list of values
                # if parsed condition verifies parsing is succeeding before writing values
                if parsed:
                    rep_writer.writerow(parsed)
                    rep_file.flush() # flush() forces Python to write its internal buffer 
                    # to disc immediately, rather than waiting for the buffer to fill up
                    # ensuring data ins't lost if the program crashes
                               
            # --- Branch 2: Other comment lines ---
            # These may be useful, so print them, but don't write to csv
            elif line.startswith('#'):
                print(f" {line}")
                continue

            # --- Branch 3: raw data lines ---
            # These lines should be raw data:
            # 1111, 3.333, 2.222, 0 
            else:
                # this try/except logic prevents more malformed lines from slipping through
                try:
                    parts = line.split(',') # splits line into a list by commas

                    if len(parts) == 4: #ensures there are only the 4 items we expect
                        raw_writer.writerow(parts)

                        if int(parts[0]) % 1250 == 0:
                            raw_file.flush() # flush file every 250 samples
                except ValueError:
                    pass
    
    except KeyboardInterrupt:
        # runs when Ctrl+c is pressed
        print("\n\nLogging stopped.")
        print(f"Session saved to: {OUTPUT_DIR}")

    finally: # finally will always run

        # flush remaining data
        raw_file.flush()
        rep_file.flush()
        # close data
        raw_file.close()
        rep_file.close()

        if 'ser' in locals() and ser.is_open: # closes the serial connection if it was opened
            ser.close()
            print("Serial port closed.")


# This logic verifies that this is the file being run, rather 
# than other files using functions imported from this file
if __name__ == '__main__':
    #STEP 1: find which port the ESP32 is on
    port = find_esp32_port()
    #STEP 2: start the logging process
    run_logger(port)

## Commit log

2026-09-20 Changed to 4x for quadrature
    [2026-06-16_15-18_raw.csv, 2026-06-16_15-18_reps.csv, 2026-06-16_15-23_raw.csv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]
2026-09-20 changed calibration
2026-09-23 V1 Hardware Files
    [ScreenBracket.SLDPRT, VBT_Container_Base.SLDPRT, VBT_Container_Lid.SLDPRT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]
2026-09-30 Clean up repo: ignore build files, rewrite README, fix calibration script
    [vbt_kicad_pcb.kicad_pcb, vbt_kicad_pcb.kicad_sch]
2026-09-30 added v1 wiring diagram
    [vbt_v1_schematic.kicad_pcb, vbt_v1_schematic.kicad_sch]
2026-09-30 upload: power_circuit.md
    power_circuit.md contains all of the information for wiring the complete power circuit.
2026-09-30 fix: added logic so that reps are only detected on ascent. In the future, I may change so that it can measure both, or one or the other. For now, it is only the ascent.
    [vbt_v1_schematic.kicad_sch]
2026-10-02 update: pcb layout complete
    [vbt_v1_schematic.kicad_sch]
2026-10-02 added vbt schematic to docs
2026-10-02 changed bom
    [v_1_bom.csv.csv]
2026-10-02 bom change
    [v_1_bom.csv]
2026-10-02 bom update
    [v_1_bom.csv.csv]
2026-10-08 Updated v2 schematics
    [vbt_kicad_pcb.kicad_sch]
2026-10-08 Add KiCad rev A project
    [vbt_kicad_pcb.kicad_pcb, vbt_kicad_pcb.kicad_sch]
2026-10-08 fix: moved cad files
    [ScreenBracket.SLDPRT, VBT_Container_Base.SLDPRT, VBT_Container_Lid.SLDPRT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]
2026-10-08 moved v2 pcb files
    [vbt_kicad_pcb.kicad_pcb, vbt_kicad_pcb.kicad_sch, vbt_v1_schematic.kicad_pcb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]
2026-10-08 fix: delete old un needed files
    [vbt_kicad_pcb.kicad_sch]
2026-10-08 fix: renamed flies to clean up repository
    [v_1_bom.csv, vbt_kicad_pcb.kicad_pcb, vbt_kicad_pcb.kicad_sch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]
2026-10-12 Updated Schematics for a 3/4/5/5 connection scheme to make sure items aren't plugged into the incorrect holes
2026-10-13 Added off_board wiring diagram and cleaned up main schematic
2026-10-13 updated schematics
2026-10-13 updated schematic
2026-10-16 updated pcb schematic for finalized BOM
2026-10-24 updated pcb layout
2026-10-24 pcb update
2026-10-25 added reset button connector to diagram and pcb layout
2026-10-25 updated pcb
2026-10-29 Update link to single battery holder to be long enough to hold protected cells v_1_bom.csv
2026-11-02 fix: added sensor class to handle any future sensor migration. also added debounce to the reset button.
2026-11-02 update: changed functionality of calibration.py
2026-11-03 added vbt pcb bom
2026-11-09 update: added new schematic to include 2.8" touchscreen
